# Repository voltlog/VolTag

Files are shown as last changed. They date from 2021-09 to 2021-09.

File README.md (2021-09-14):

# VolTag
VolTag is an FT232R based breakout board that enhances the FTDI MPSSE (Multi-Protocol Synchronous Serial Engine) to provide the user with a USB to JTAG (SPI, I2C, bit-bang) interface which also has a built-in voltage level translator on the JTAG lines for interfacing to devices that run at a different voltage (between 1.5-5V).

revA has an important bug that prevents communication through the voltage level translating IC because of an incorrect direction configuration. The JTAG interface is still functional through the regular 0.1inch header IO connected directly to the FT232H but you loose the ability to do voltage translation. This issue will be address in revB.

More info about this project in [Voltlog #379](https://youtu.be/LoFzdOF0YcY).

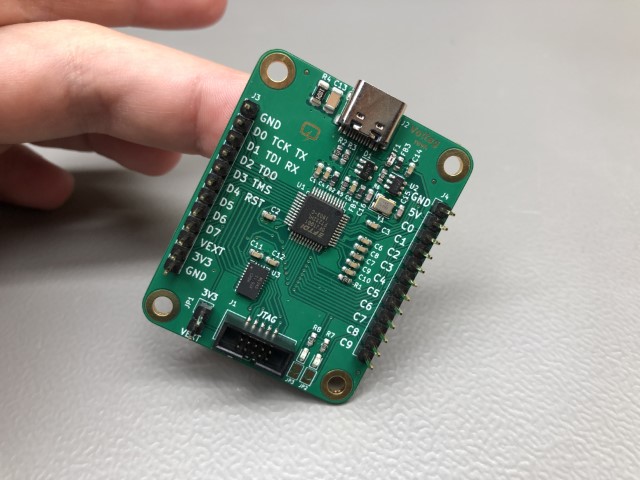
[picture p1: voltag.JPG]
Image of the assembled PCB


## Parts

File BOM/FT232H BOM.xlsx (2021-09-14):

FT232H Bill of Material
Ref | Qnty | Value | Cmp name | Footprint | Description | LCSC # | Digikey #
C1, C2, C3, C4, C5, C6, C8, C9, C10, C11, C12, C14, | 12 | 0.1uF | C | Capacitor_SMD:C_0603_1608Metric | Unpolarized capacitor | C1591
C7, | 1 | 4.7uF | C | Capacitor_SMD:C_0603_1608Metric | Unpolarized capacitor | C19666
C13, | 1 | 4.7nF | C | Capacitor_SMD:C_1206_3216Metric | Unpolarized capacitor | C1621
C15, C16, | 2 | 20pF | C | Capacitor_SMD:C_0603_1608Metric | Unpolarized capacitor | C1648
D1, | 1 | SP0504BAHT | SP0504BAHT | Package_TO_SOT_SMD:SOT-23-5 | TVS Diode Array, 5.5V Standoff, 4 Channels, SOT-23-5 package | C10675
D2, | 1 | Red | LED_ALT | LED_SMD:LED_0603_1608Metric | Light emitting diode, filled shape | C84263
D3, | 1 | Green | LED_ALT | LED_SMD:LED_0603_1608Metric | Light emitting diode, filled shape | C84267
F1, | 1 | 0.5A | Polyfuse | Fuse:Fuse_0603_1608Metric | Resettable fuse, polymeric positive temperature coefficient | C210357
FB1, FB2, FB3, | 3 | 600R | Ferrite_Bead_Small | Inductor_SMD:L_0603_1608Metric | Ferrite bead, small symbol | C107335
J1, | 1 | JTAG | Conn_ARM_JTAG_SWD_10 | voltlog:PinHeader_IDC_2x05_P1.27mm | Cortex Debug Connector, standard ARM Cortex-M SWD and JTAG interface | - | 1175-1629-ND
J2, | 1 | USB_C_Receptacle_USB2.0 | USB_C_Receptacle_USB2.0 | voltlog:TYPE-C-31-M-12 | USB 2.0-only Type-C Receptacle connector | C165948
J3, J4, | 2 | Conn_01x12 | Conn_01x12 | Connector_PinHeader_2.54mm:PinHeader_1x12_P2.54mm_Vertical | Generic connector, single row, 01x12, script generated (kicad-library-utils/schlib/autogen/connector/) | C225487
JP1, | 1 | NO | Jumper_NC_Small | Connector_PinHeader_2.54mm:PinHeader_1x02_P2.54mm_Vertical | Jumper, normally closed, small symbol | C358684
JP2, JP3, | 2 | NC | Jumper_NC_Small | Jumper:SolderJumper-2_P1.3mm_Open_TrianglePad1.0x1.5mm | Jumper, normally closed, small symbol | DNP
R1, R5, | 2 | 12K | R_US | Resistor_SMD:R_0603_1608Metric | Resistor, US symbol | C22790
R2, R3, | 2 | 5K1 | R_US | Resistor_SMD:R_0603_1608Metric | Resistor, US symbol | C105580
R4, | 1 | 1M | R_US | Resistor_SMD:R_1206_3216Metric | Resistor, US symbol | C105578
R6, | 1 | 2K | R_US | Resistor_SMD:R_0603_1608Metric | Resistor, US symbol | C22975
R7, R8, | 2 | 1K | R_US | Resistor_SMD:R_0603_1608Metric | Resistor, US symbol | C21190
U1, | 1 | FT232H | FT232H | Package_QFP:LQFP-48_7x7mm_P0.5mm | Hi Speed Single Channel USB UART/FIFO, LQFP/QFN-48 (Voltlog symbol) | C51997
U2, | 1 | 93LC56BT | 93LCxxBxxOT | Package_TO_SOT_SMD:SOT-23-6 | Serial EEPROM, 93 Series, 2.5V, SOT-23-6 | C190271
U3, | 1 | SN74AVC8T245RHL | SN74AVC8T245RHL | voltlog:Texas_PVQFN-N24 | 8-Bit Dual-Supply Bus Transceiver With Configurable Voltage Translation and 3-State Outputs, VQFN24 | C105245
Y1, | 1 | 12MHz | Crystal_GND24 | Crystal:Crystal_SMD_3225-4Pin_3.2x2.5mm | Four pin crystal, GND on pins 2 and 4 | C9002

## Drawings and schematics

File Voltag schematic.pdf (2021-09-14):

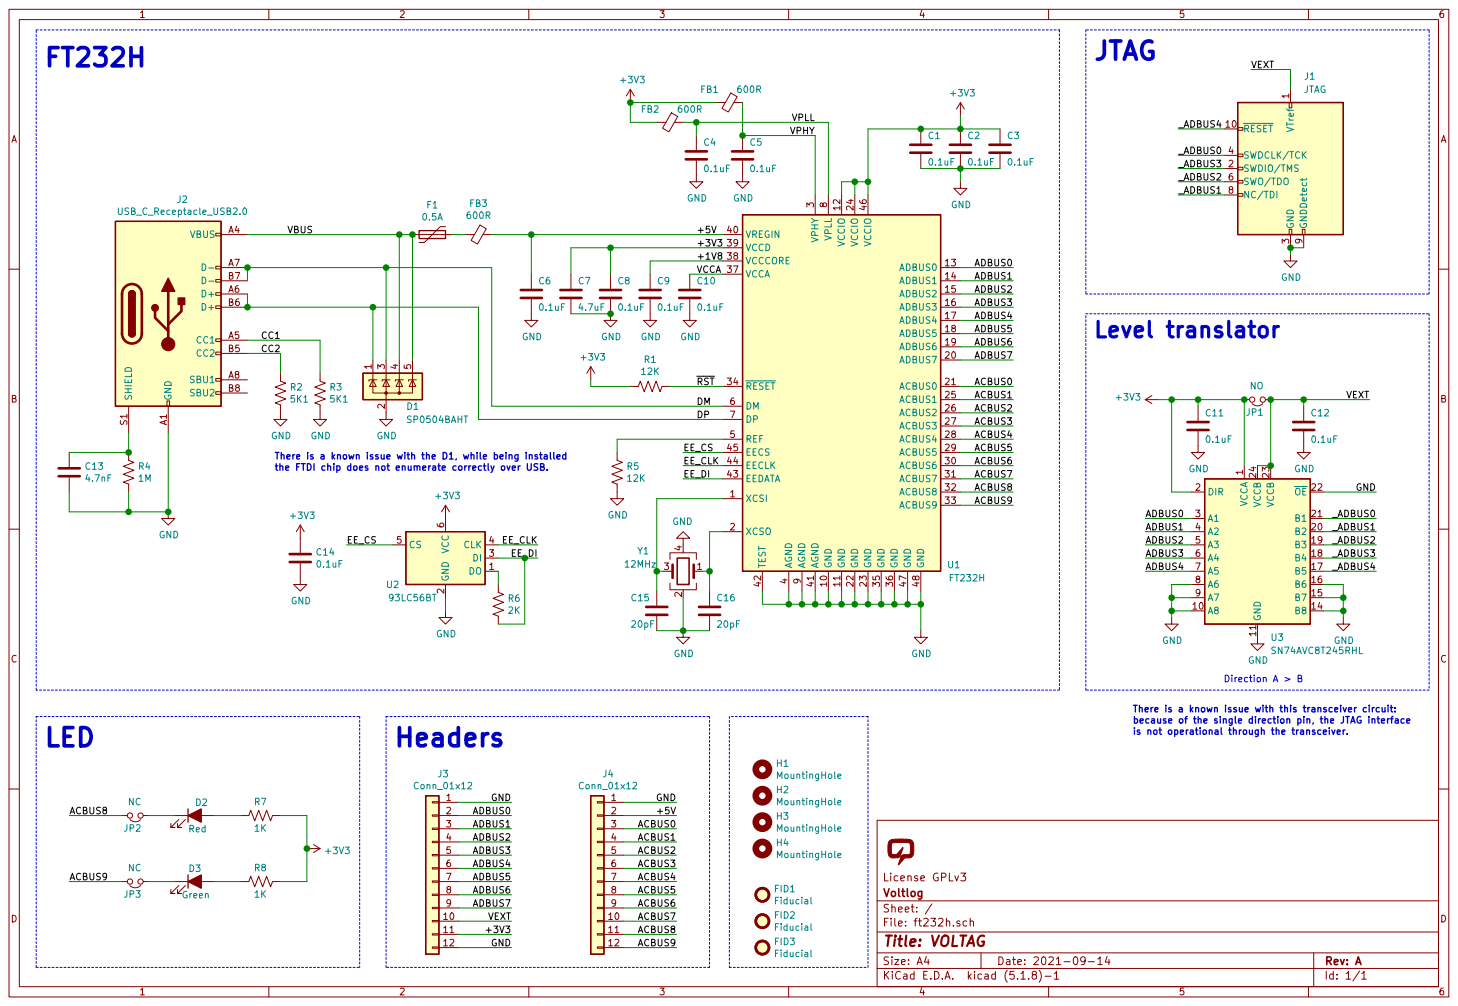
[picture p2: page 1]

3 SWDCLK/TCK 4 SWO/TDO 6 NC/TDI 8 GNDDetect 9 J1

4 VREGIN 40 AGND 41 TEST 42 EEDATA 43 EECLK 44 EECS 45 VCCIO 46 GND 47 GND 48 REF 5 DM 6 DP 7 VPLL

3 ACBUS6 30 ACBUS7 31 ACBUS8 32 ACBUS9 33 RESET 34 GND 35 GND 36 VCCA 37 VCCCORE 38 VCCD 39 AGND

There is a known issue with the D1, while being installed
the FTDI chip does not enumerate correctly over USB.

1 A8 10 GND 11 B8 14 B7 15 B6 16 B5 17 B4 18 B3 19 DIR 2 B2 20 B1 21 OE 22 VCCB 23 VCCB 24 A1 3 A2 4 A3 5 A4 6 A5 7 A6 8 A7 9 U3SN74AVC8T245RHL

2 DI 3 CLK 4 CS 5 VCC

is not operational through the transceiver. Direction A > B

License GPLv3
File: ft232h.sch Sheet: / Voltlog

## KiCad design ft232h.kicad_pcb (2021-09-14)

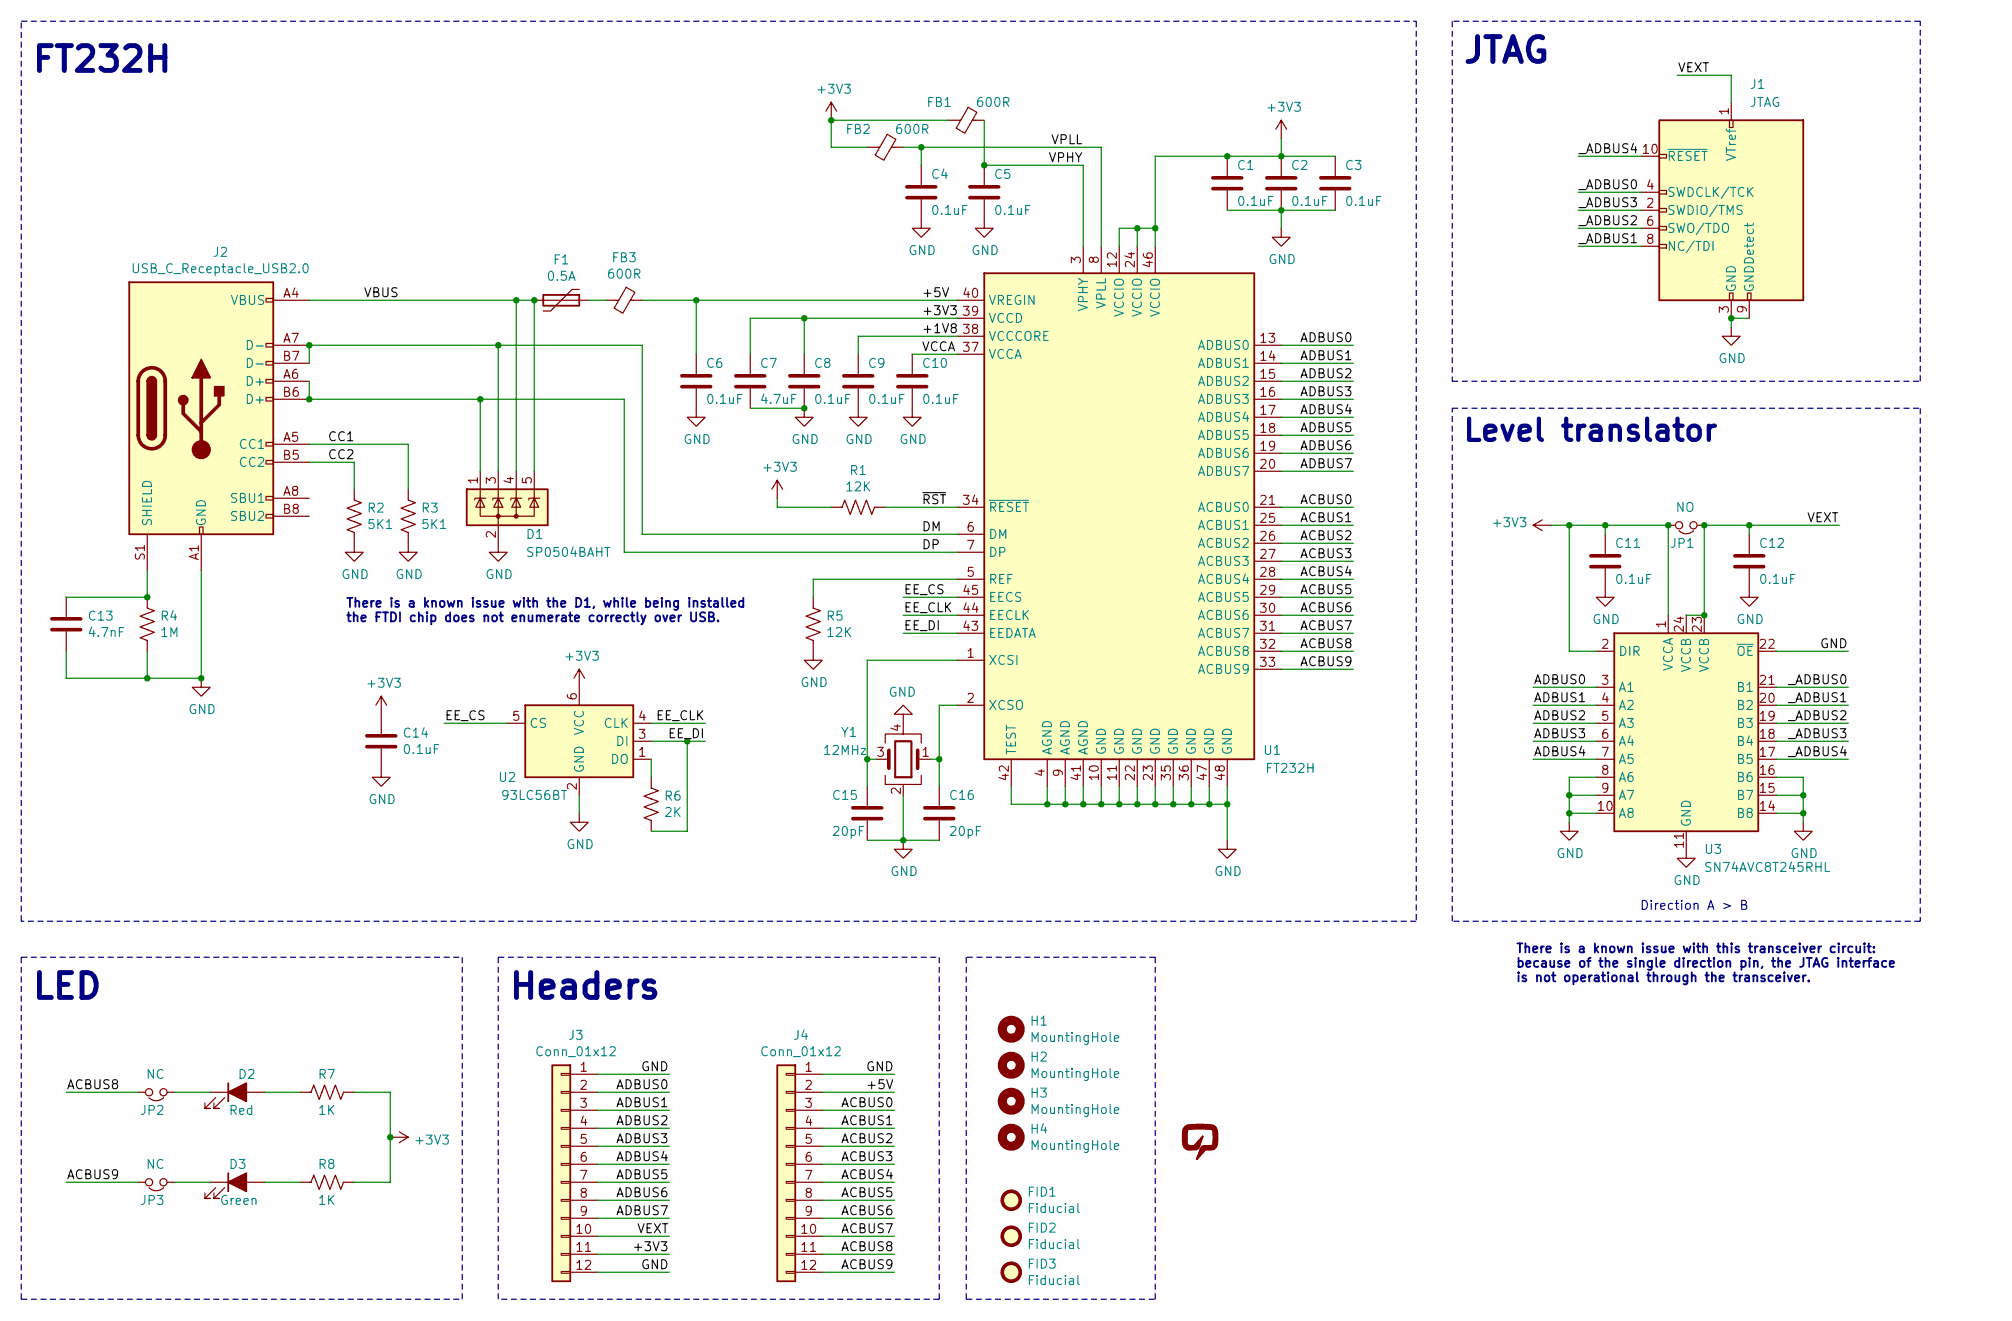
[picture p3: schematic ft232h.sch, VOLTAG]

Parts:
C1, C2, C3, C4, C5, C6, C8, C9, C10, C11, C12, C14: 0.1uF; C_0603_1608Metric
C7: 4.7uF; C_0603_1608Metric
C13: 4.7nF; C_1206_3216Metric
C15, C16: 20pF; C_0603_1608Metric
D1: SP0504BAHT; SOT-23-5
D2: Red; LED_0603_1608Metric
D3: Green; LED_0603_1608Metric
F1: 0.5A; Fuse_0603_1608Metric
FB1, FB2, FB3: 600R; L_0603_1608Metric
FID1, FID2, FID3: Fiducial; Fiducial_0.5mm_Mask1mm
H1, H2, H3, H4: MountingHole; MountingHole_3.2mm_M3_DIN965_Pad
J1: JTAG; PinHeader_IDC_2x05_P1.27mm
J2: USB_C_Receptacle_USB2.0; TYPE-C-31-M-12
J3, J4: Conn_01x12; PinHeader_1x12_P2.54mm_Vertical
JP1: NO; PinHeader_1x02_P2.54mm_Vertical
JP2, JP3: NC; SolderJumper-2_P1.3mm_Open_TrianglePad1.0x1.5mm
R1, R5: 12K; R_0603_1608Metric
R2, R3: 5K1; R_0603_1608Metric
R4: 1M; R_1206_3216Metric
R6: 2K; R_0603_1608Metric
R7, R8: 1K; R_0603_1608Metric
U1: FT232H; LQFP-48_7x7mm_P0.5mm
U2: 93LC56BT; SOT-23-6
U3: SN74AVC8T245RHL; Texas_PVQFN-N24
V1: VOLTLOG_LOGO; voltlog_mask_3mm
Y1: 12MHz; Crystal_SMD_3225-4Pin_3.2x2.5mm

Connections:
+3V3: C1.1, C2.1, C3.1, C7.1, C8.1, C11.1, C14.1, FB1.2, FB2.2, J3.11, JP1.2, R1.2, R7.2, R8.2, U1.12 (VCCIO), U1.24 (VCCIO), U1.39 (VCCD), U1.46 (VCCIO), U2.6 (VCC), U3.1 (VCCA), U3.2 (DIR)
/+1V8: C9.1, U1.38 (VCCCORE)
/+5V: C6.1, FB3.1, J4.2, U1.40 (VREGIN)
/ACBUS0: J4.3, U1.21 (ACBUS0)
/ACBUS1: J4.4, U1.25 (ACBUS1)
/ACBUS2: J4.5, U1.26 (ACBUS2)
/ACBUS3: J4.6, U1.27 (ACBUS3)
/ACBUS4: J4.7, U1.28 (ACBUS4)
/ACBUS5: J4.8, U1.29 (ACBUS5)
/ACBUS6: J4.9, U1.30 (ACBUS6)
/ACBUS7: J4.10, U1.31 (ACBUS7)
/ACBUS8: J4.11, JP2.2, U1.32 (ACBUS8)
/ACBUS9: J4.12, JP3.2, U1.33 (ACBUS9)
/ADBUS0: J3.2, U1.13 (ADBUS0), U3.3 (A1)
/ADBUS1: J3.3, U1.14 (ADBUS1), U3.4 (A2)
/ADBUS2: J3.4, U1.15 (ADBUS2), U3.5 (A3)
/ADBUS3: J3.5, U1.16 (ADBUS3), U3.6 (A4)
/ADBUS4: J3.6, U1.17 (ADBUS4), U3.7 (A5)
/ADBUS5: J3.7, U1.18 (ADBUS5)
/ADBUS6: J3.8, U1.19 (ADBUS6)
/ADBUS7: J3.9, U1.20 (ADBUS7)
/CC1: J2.A5 (CC1), R3.1
/CC2: J2.B5 (CC2), R2.1
/DM: D1.3 (K), J2.A7 (D-), J2.B7 (D-), U1.6 (DM)
/DP: D1.1 (K), J2.A6 (D+), J2.B6 (D+), U1.7 (DP)
/EE_CLK: U1.44 (EECLK), U2.4 (CLK)
/EE_CS: U1.45 (EECS), U2.5 (CS)
/EE_DI: R6.2, U1.43 (EEDATA), U2.3 (DI)
/VBUS: D1.4 (K), D1.5 (K), F1.2, J2.A4 (VBUS), J2.A9 (VBUS), J2.B4 (VBUS), J2.B9 (VBUS)
/VCCA: C10.1, U1.37 (VCCA)
/VEXT: C12.1, J1.1 (VTref), J3.10, JP1.1, U3.23 (VCCB), U3.24 (VCCB)
/VPHY: C5.1, FB1.1, U1.3 (VPHY)
/VPLL: C4.1, FB2.1, U1.8 (VPLL)
/_ADBUS0: J1.4 (SWDCLK/TCK), U3.21 (B1)
/_ADBUS1: J1.8 (NC/TDI), U3.20 (B2)
/_ADBUS2: J1.6 (SWO/TDO), U3.19 (B3)
/_ADBUS3: J1.2 (SWDIO/TMS), U3.18 (B4)
/_ADBUS4: J1.10 (~RESET~), U3.17 (B5)
/~RST: R1.1, U1.34 (~RESET)
GND: C1.2, C2.2, C3.2, C4.2, C5.2, C6.2, C7.2, C8.2, C9.2, C10.2, C11.2, C12.2, C13.2, C14.2, C15.2, C16.2, D1.2 (A), J1.3 (GND), J1.5 (GND), J1.9 (GNDDetect), J2.A1 (GND), J2.A12 (GND), J2.B1 (GND), J2.B12 (GND), J3.1, J3.12, J4.1, R2.2, R3.2, R4.2, R5.2, U1.4 (AGND), U1.9 (AGND), U1.10 (GND), U1.11 (GND), U1.22 (GND), U1.23 (GND), U1.35 (GND), U1.36 (GND), U1.41 (AGND), U1.42 (TEST), U1.47 (GND), U1.48 (GND), U2.2 (GND), U3.8 (A6), U3.9 (A7), U3.10 (A8), U3.11 (GND), U3.12 (GND), U3.13 (GND), U3.14 (B8), U3.15 (B7), U3.16 (B6), U3.22 (~OE), U3.25 (GND), Y1.2, Y1.4
unnamed: C13.1, J2.S1 (SHIELD), R4.1
unnamed: C15.1, U1.1 (XCSI), Y1.3
unnamed: C16.1, U1.2 (XCSO), Y1.1
unnamed: D2.1 (K), JP2.1
unnamed: D2.2 (A), R7.1
unnamed: D3.1 (K), JP3.1
unnamed: D3.2 (A), R8.1
unnamed: F1.1, FB3.2
unnamed: R5.1, U1.5 (REF)
unnamed: R6.1, U2.1 (DO)

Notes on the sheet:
FT232H
JTAG
Headers
LED
Level translator
Direction A > B
There is a known issue with this transceiver circuit: because of the single direction pin, the JTAG interface is not operational through the transceiver.
There is a known issue with the D1, while being installed the FTDI chip does not enumerate correctly over USB.

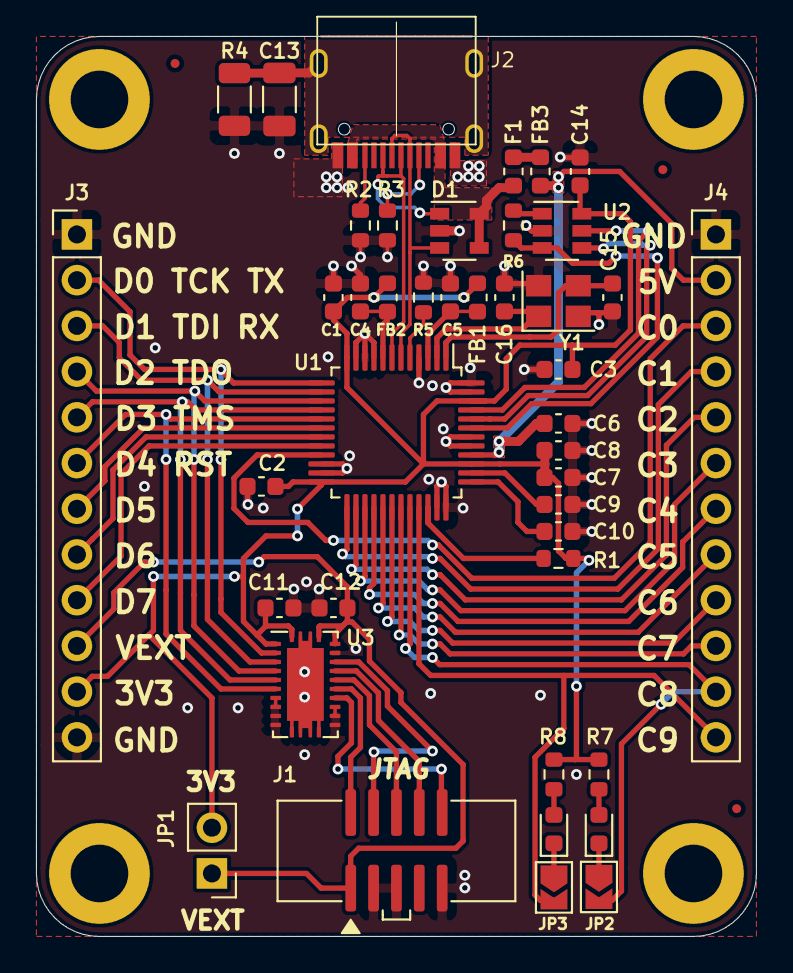
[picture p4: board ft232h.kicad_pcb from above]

Board: 2 copper layers, 40.0 x 50.0 mm, 50 parts (0 on the bottom side), 50 nets.
